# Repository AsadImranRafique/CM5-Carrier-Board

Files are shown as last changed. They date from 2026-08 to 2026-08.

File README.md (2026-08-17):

# CM4/CM5 Carrier Board V1

Production build of a compact carrier board for the Raspberry Pi Compute Module 4 and Compute Module 5. The board combines USB-C data and power, Ethernet, 25 W PoE input, M.2 storage and essential peripheral connections in a 120 mm × 40 mm form factor.

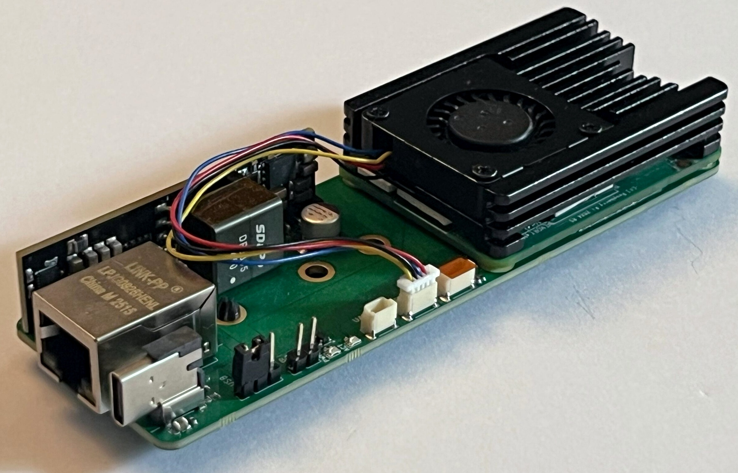
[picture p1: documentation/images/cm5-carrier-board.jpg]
Assembled CM4/CM5 Carrier Board V1


## Key Features

- Raspberry Pi Compute Module 4 and Compute Module 5 support
- Two 100-pin Hirose board-to-board connectors
- 120 mm × 40 mm board outline
- Six-layer PCB
- USB-C for data and 5 V at up to 3 A power input
- RJ45 Ethernet MagJack
- 25 W PoE powered-device input
- Jumper-selectable USB-C or PoE power input
- M.2 M-Key connector with support for 2230, 2242 and 2260 modules
- microSD card socket for Compute Module Lite variants
- 3-pin UART JST connector
- 3-pin I²C JST connector
- 3-pin PWM fan JST connector
- PWR and ACT indicator LEDs

## Power Input

The carrier board can be powered through either USB-C or PoE. The active input is selected using the onboard power-selection jumper.

The USB-C input provides 5 V at up to 3 A and uses CC pull-down resistors for source detection. The PoE interface operates as a 25 W powered device through the Ethernet connection.

## Storage

The M.2 M-Key interface supports 2230, 2242 and 2260 module sizes. A microSD card socket is provided for CM4 Lite and CM5 Lite variants without onboard eMMC storage.

## Peripheral Connections

UART, I²C and PWM fan connections are exposed through dedicated 3-pin JST connectors. PWR and ACT LEDs provide visible system-status indication.

## Repository Contents

This repository contains the KiCad design sources for the production V1 board, including:

- Schematic and PCB layout
- Project symbol and footprint libraries
- Component 3D models

## Opening the Project

1. Install [KiCad](https://www.kicad.org/).
2. Clone or download this repository.
3. Open `CM5Carrier.kicad_pro`.

## License

This hardware design is licensed under the [Apache License 2.0](LICENSE).

## Author

Designed by [Asad Imran](https://github.com/AsadImranRafique).

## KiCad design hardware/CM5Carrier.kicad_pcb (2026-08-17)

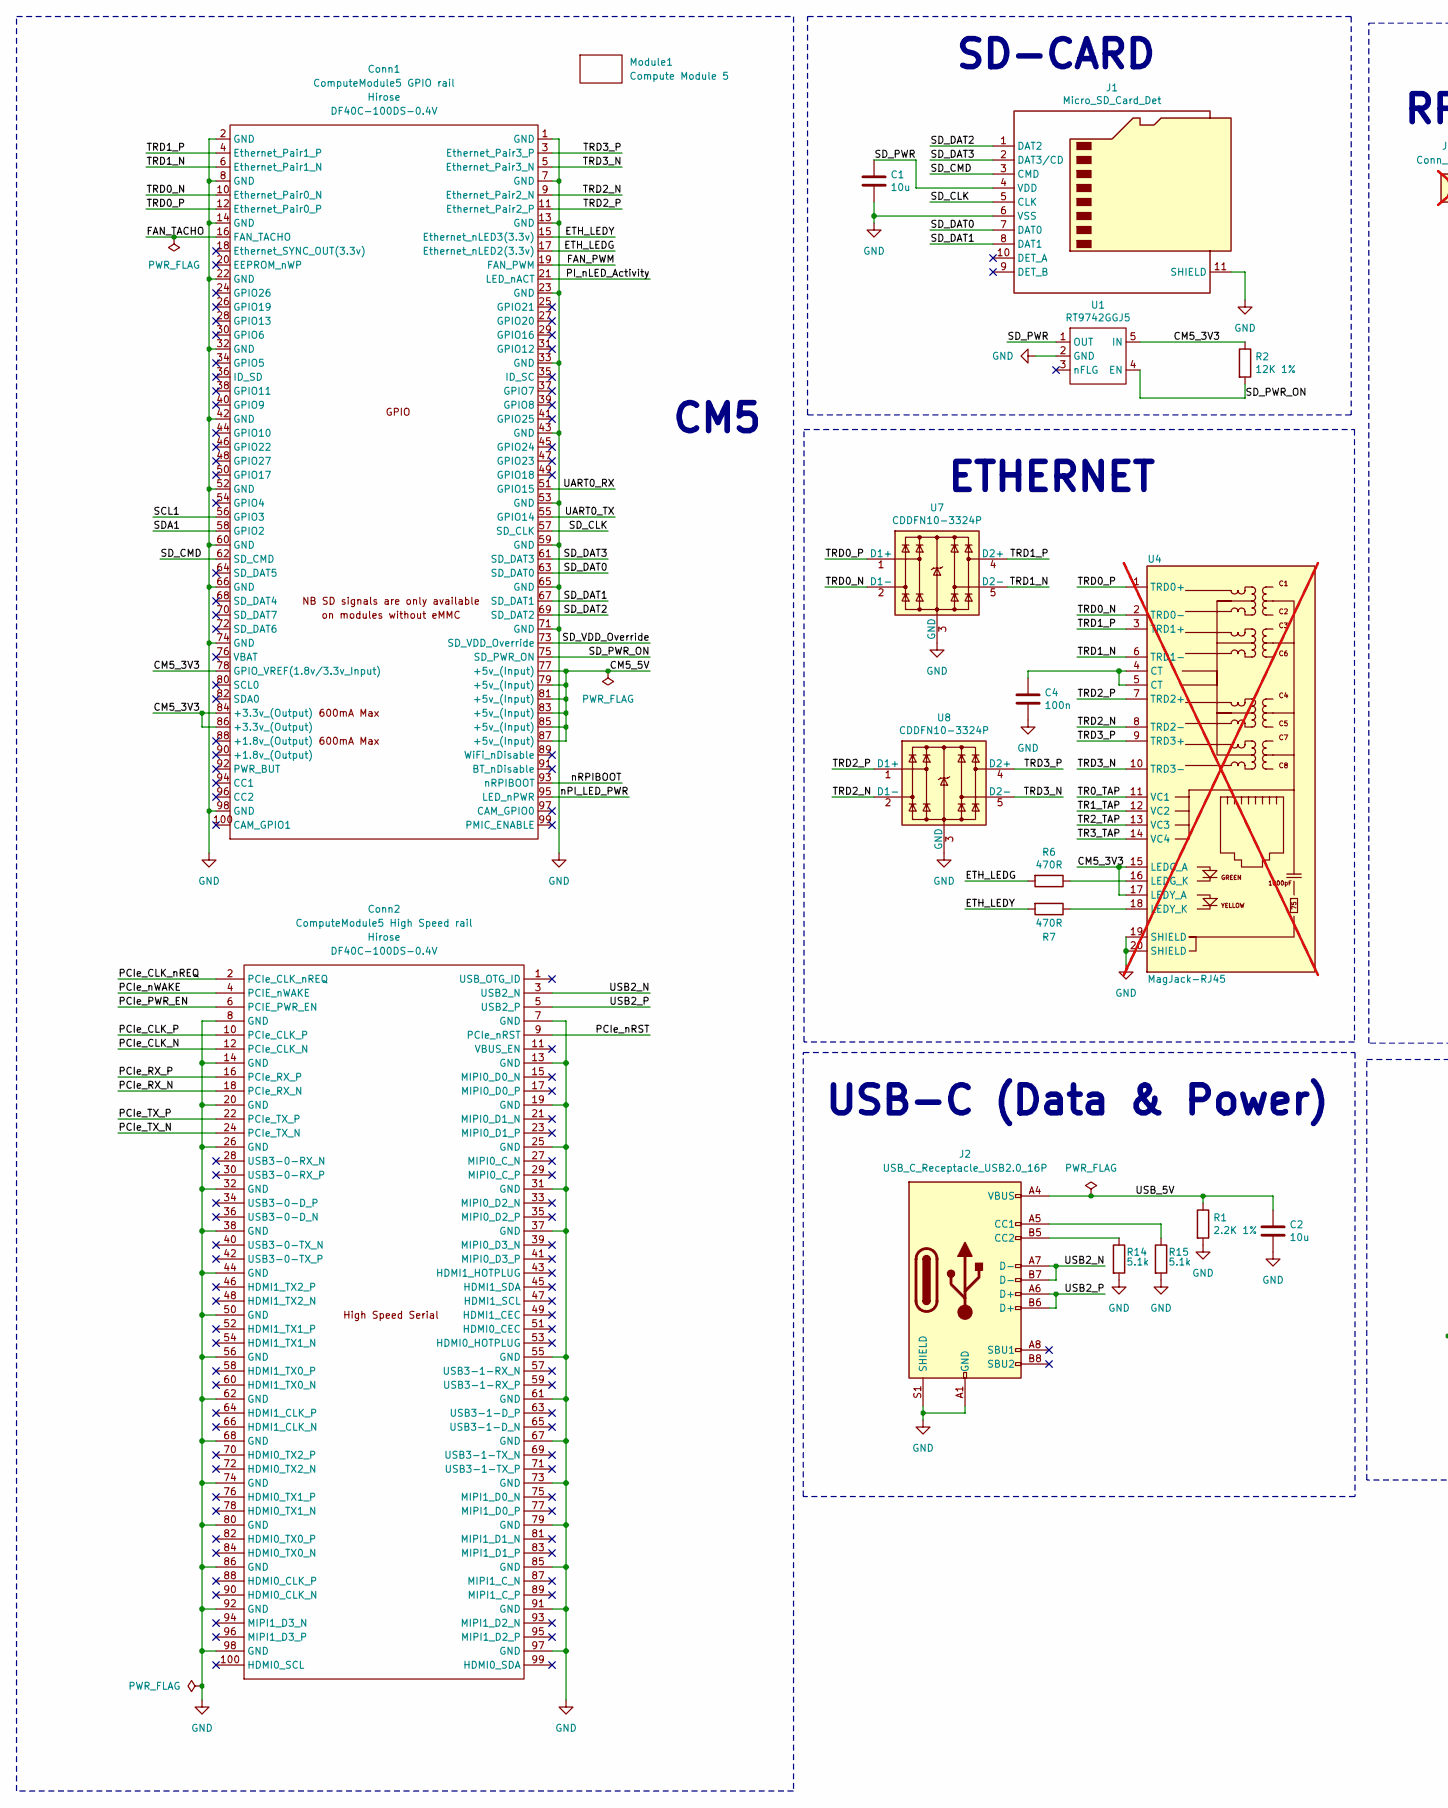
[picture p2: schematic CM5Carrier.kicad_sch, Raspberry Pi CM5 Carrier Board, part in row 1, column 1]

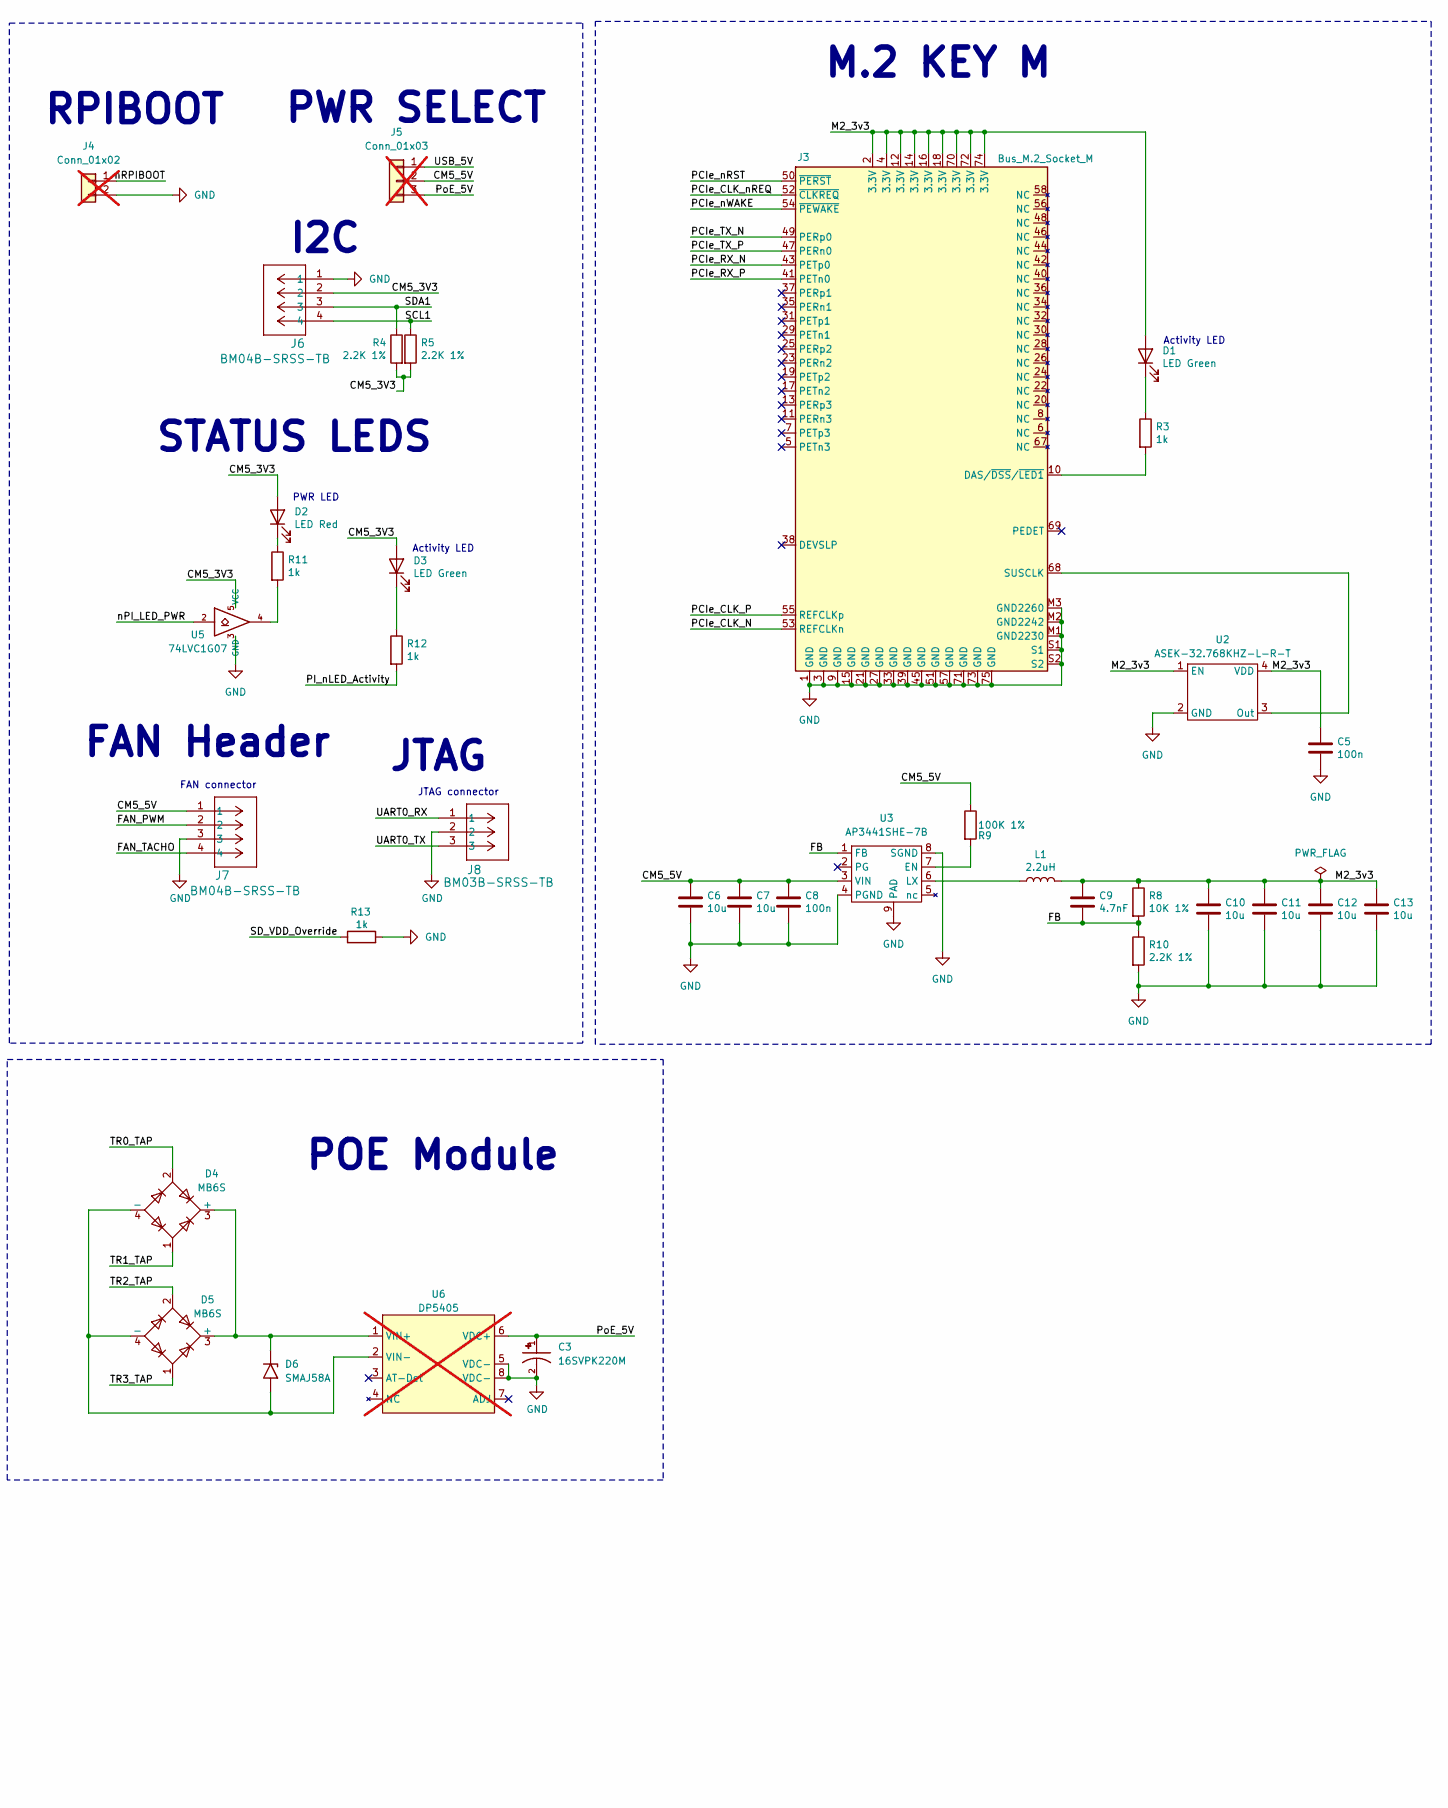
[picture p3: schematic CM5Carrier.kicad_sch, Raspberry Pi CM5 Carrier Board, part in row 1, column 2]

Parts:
C1, C2, C6, C7, C10, C11, C12, C13: 10u; C_0805_2012Metric; Part Number GRM21BR71A106KA73L
C3: 16SVPK220M; CAP_16SVPK220M; Part Number 16SVPK220M
C4, C5, C8: 100n; C_0402_1005Metric; Part Number EMK105B7104KV-F
C9: 4.7nF; C_0402_1005Metric; Part Number CC0402KRX7R9BB472
Conn1: ComputeModule5 GPIO rail; CONN_DF40C-100DS-0.4V51_HIR; Part Number DF40C-100DS-0.4V
Conn2: ComputeModule5 High Speed rail; CONN_DF40C-100DS-0.4V51_HIR; Part Number DF40C-100DS-0.4V
D1, D3: LED Green; LED_0603_1608Metric; Part Number LTST-C190GKT
D2: LED Red; LED_0603_1608Metric; Part Number LTST-C190KRKT
D4, D5: MB6S; TO-269AA; Part Number MB6S
D6: SMAJ58A; D_SMA; Part Number SMAJ58A
J1: Micro_SD_Card_Det; SDCARD_MOLEX_503398-1892; Part Number 5033981892
J2: USB_C_Receptacle_USB2.0_16P; USB4205-GF-A; Part Number USB4205-GF-A
J3: Bus_M.2_Socket_M; M.2 M Key socket; Part Number MDT320M03001
J4: Conn_01x02; PinHeader_1x02_P2.54mm_Vertical; Part Number G800W306018EU; not fitted
J5: Conn_01x03; PinHeader_1x03_P2.54mm_Vertical; Part Number G800W305018EU; not fitted
J6, J7: BM04B-SRSS-TB; JST_SH_BM04B-SRSS-TB_1x04-1MP_P1.00mm_Vertical; Part Number BM04B-SRSS-TB
J8: BM03B-SRSS-TB; JST_SH_BM03B-SRSS-TB_1x03-1MP_P1.00mm_Vertical; Part Number BM03B-SRSS-TB
L1: 2.2uH; L_Bourns_SRP5030CC; Part Number SRP5030CC-2R2M
Module1: Compute Module 5; Raspberry-Pi-5-Compute-Module
R1, R4, R5, R10: 2.2K 1%; R_0402_1005Metric; Part Number RC0402FR-072K2L
R2: 12K 1%; R_0402_1005Metric; Part Number RC0402FR-0712KL
R3, R11, R12, R13: 1k; R_0402_1005Metric; Part Number RC0402FR-071KL
R6, R7: 470R; R_0402_1005Metric; Part Number RC0402FR-07470RL
R8: 10K 1%; R_0402_1005Metric; Part Number RC0402FR-0710KL
R9: 100K 1%; R_0402_1005Metric; Part Number RC0402FR-07100KL
R14, R15: 5.1k; R_0603_1608Metric; Part Number RC0603FR-075K1L
U1: RT9742GGJ5; SOT-23-5; Part Number RT9742GGJ5
U2: ASEK-32.768KHZ-L-R-T; Crystal_SMD_3225-4Pin_3.2x2.5mm; Part Number ASEK-32.768KHZ-L-R-T
U3: AP3441SHE-7B; DFN-8-1EP_2x2mm_P0.5mm_EP1.05x1.75mm; Part Number AP3441SHE-7B
U4: MagJack-RJ45; TRJG0926HENL; Part Number LPJG0926HENL; not fitted
U5: 74LVC1G07; SOT-353_SC-70-5; Part Number 74LVC1G07
U6: DP5405; not fitted
U7, U8: CDDFN10-3324P; USON-10_2.5x1.0mm_P0.5mm; Part Number CDDFN10-3324P

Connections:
/CM5_3V3: Conn1.78 (GPIO_VREF(1.8v/3.3v_Input)), Conn1.84 (+3.3v_(Output)), Conn1.86 (+3.3v_(Output)), D2.2 (A), D3.2 (A), J6.2, R2.1, R4.2, R5.2, U1.5 (IN), U4.15 (LEDG_A), U4.17 (LEDY_A), U5.5 (VCC)
/CM5_5V: C6.1, C7.1, C8.1, Conn1.77 (+5v_(Input)), Conn1.79 (+5v_(Input)), Conn1.81 (+5v_(Input)), Conn1.83 (+5v_(Input)), Conn1.85 (+5v_(Input)), Conn1.87 (+5v_(Input)), J5.2, J7.1, R9.1, U3.3 (VIN)
/ETH_LEDG: Conn1.17 (Ethernet_nLED2(3.3v)), R6.2
/ETH_LEDY: Conn1.15 (Ethernet_nLED3(3.3v)), R7.2
/FAN_PWM: Conn1.19 (FAN_PWM), J7.2
/FAN_TACHO: Conn1.16 (FAN_TACHO), J7.4
/FB: C9.2, R8.2, R10.1, U3.1 (FB)
/M2_3v3: C5.1, C9.1, C10.1, C11.1, C12.1, C13.1, D1.2 (A), J3.2 (3.3V), J3.4 (3.3V), J3.12 (3.3V), J3.14 (3.3V), J3.16 (3.3V), J3.18 (3.3V), J3.70 (3.3V), J3.72 (3.3V), J3.74 (3.3V), L1.2, R8.1, U2.1 (EN), U2.4 (VDD)
/PCIe_CLK_N: Conn2.12 (PCIe_CLK_N), J3.53 (REFCLKn)
/PCIe_CLK_P: Conn2.10 (PCIe_CLK_P), J3.55 (REFCLKp)
/PCIe_CLK_nREQ: Conn2.2 (PCIe_CLK_nREQ), J3.52 (~CLKREQ)
/PCIe_PWR_EN: Conn2.6 (PCIE_PWR_EN)
/PCIe_RX_N: Conn2.18 (PCIe_RX_N), J3.43 (PETp0)
/PCIe_RX_P: Conn2.16 (PCIe_RX_P), J3.41 (PETn0)
/PCIe_TX_N: Conn2.24 (PCIe_TX_N), J3.49 (PERp0)
/PCIe_TX_P: Conn2.22 (PCIe_TX_P), J3.47 (PERn0)
/PCIe_nRST: Conn2.9 (PCIe_nRST), J3.50 (~PERST)
/PCIe_nWAKE: Conn2.4 (PCIE_nWAKE), J3.54 (~PEWAKE)
/PI_nLED_Activity: Conn1.21 (LED_nACT), R12.2
/PoE_5V: C3.1, J5.3, U6.6 (VDC+)
/SCL1: Conn1.56 (GPIO3), J6.4, R5.1
/SDA1: Conn1.58 (GPIO2), J6.3, R4.1
/SD_CLK: Conn1.57 (SD_CLK), J1.5 (CLK)
/SD_CMD: Conn1.62 (SD_CMD), J1.3 (CMD)
/SD_DAT0: Conn1.63 (SD_DAT0), J1.7 (DAT0)
/SD_DAT1: Conn1.67 (SD_DAT1), J1.8 (DAT1)
/SD_DAT2: Conn1.69 (SD_DAT2), J1.1 (DAT2)
/SD_DAT3: Conn1.61 (SD_DAT3), J1.2 (DAT3/CD)
/SD_PWR: C1.1, J1.4 (VDD), U1.1 (OUT)
/SD_PWR_ON: Conn1.75 (SD_PWR_ON), R2.2, U1.4 (EN)
/SD_VDD_Override: Conn1.73 (SD_VDD_Override), R13.1
/TR0_TAP: D4.2, U4.11 (VC1)
/TR1_TAP: D4.1, U4.12 (VC2)
/TR2_TAP: D5.2, U4.13 (VC3)
/TR3_TAP: D5.1, U4.14 (VC4)
/TRD0_N: Conn1.10 (Ethernet_Pair0_N), U4.2 (TRD0-), U7.2 (D1-), U7.9
/TRD0_P: Conn1.12 (Ethernet_Pair0_P), U4.1 (TRD0+), U7.1 (D1+), U7.10
/TRD1_N: Conn1.6 (Ethernet_Pair1_N), U4.6 (TRD1-), U7.5 (D2-), U7.6
/TRD1_P: Conn1.4 (Ethernet_Pair1_P), U4.3 (TRD1+), U7.4 (D2+), U7.7
/TRD2_N: Conn1.9 (Ethernet_Pair2_N), U4.8 (TRD2-), U8.2 (D1-), U8.9
/TRD2_P: Conn1.11 (Ethernet_Pair2_P), U4.7 (TRD2+), U8.1 (D1+), U8.10
/TRD3_N: Conn1.5 (Ethernet_Pair3_N), U4.10 (TRD3-), U8.5 (D2-), U8.6
/TRD3_P: Conn1.3 (Ethernet_Pair3_P), U4.9 (TRD3+), U8.4 (D2+), U8.7
/UART0_RX: Conn1.51 (GPIO15), J8.1
/UART0_TX: Conn1.55 (GPIO14), J8.3
/USB2_N: Conn2.3 (USB2_N), J2.A7 (D-), J2.B7 (D-)
/USB2_P: Conn2.5 (USB2_P), J2.A6 (D+), J2.B6 (D+)
/USB_5V: C2.1, J2.A4 (VBUS), J2.A9 (VBUS), J2.B4 (VBUS), J2.B9 (VBUS), J5.1, R1.1
/nPI_LED_PWR: Conn1.95 (LED_nPWR), U5.2
/nRPIBOOT: Conn1.93 (nRPIBOOT), J4.1
GND: C1.2, C2.2, C3.2, C4.2, C5.2, C6.2, C7.2, C8.2, C10.2, C11.2, C12.2, C13.2, Conn1.1 (GND), Conn1.2 (GND), Conn1.7 (GND), Conn1.8 (GND), Conn1.13 (GND), Conn1.14 (GND), Conn1.22 (GND), Conn1.23 (GND), Conn1.32 (GND), Conn1.33 (GND), Conn1.42 (GND), Conn1.43 (GND), Conn1.52 (GND), Conn1.53 (GND), Conn1.59 (GND), Conn1.60 (GND), Conn1.65 (GND), Conn1.66 (GND), Conn1.71 (GND), Conn1.74 (GND), Conn1.98 (GND), Conn2.7 (GND), Conn2.8 (GND), Conn2.13 (GND), Conn2.14 (GND), Conn2.19 (GND), Conn2.20 (GND), Conn2.25 (GND), Conn2.26 (GND), Conn2.31 (GND), Conn2.32 (GND), Conn2.37 (GND), Conn2.38 (GND), Conn2.44 (GND), Conn2.50 (GND), Conn2.55 (GND), Conn2.56 (GND), Conn2.61 (GND), Conn2.62 (GND), Conn2.67 (GND), Conn2.68 (GND), Conn2.73 (GND), Conn2.74 (GND), Conn2.79 (GND), Conn2.80 (GND), Conn2.85 (GND), Conn2.86 (GND), Conn2.91 (GND), Conn2.92 (GND), Conn2.97 (GND), Conn2.98 (GND), J1.6 (VSS), J1.11 (SHIELD), J2.A1 (GND), J2.A12 (GND), J2.B1 (GND), J2.B12 (GND), J2.S1 (SHIELD), J3.1 (GND), J3.3 (GND), J3.9 (GND), J3.15 (GND), J3.21 (GND), J3.27 (GND), J3.33 (GND), J3.39 (GND), J3.45 (GND), J3.51 (GND), J3.57 (GND), J3.71 (GND), J3.73 (GND), J3.75 (GND), J3.M1 (GND2230), J3.M2 (GND2242), J3.M3 (GND2260), J3.S1, J3.S2, J4.2, J6.1, J7.3, J8.2, R1.2, R10.2, R13.2, R14.2, R15.2, U1.2 (GND), U2.2 (GND), U3.4 (PGND), U3.8 (SGND), U3.9 (PAD), U4.19 (SHIELD), U4.20 (SHIELD), U5.3 (GND), U6.5 (VDC-), U6.8 (VDC-), U7.3 (GND), U7.8 (GND), U8.3 (GND), U8.8 (GND)
unnamed: C4.1, U4.4 (CT), U4.5 (CT)
unnamed: D1.1 (K), R3.1
unnamed: D2.1 (K), R11.1
unnamed: D3.1 (K), R12.1
unnamed: D4.3 (+), D5.3 (+), D6.1 (A1), U6.1 (VIN+)
unnamed: D4.4 (-), D5.4 (-), D6.2 (A2), U6.2 (VIN-)
unnamed: J2.A5 (CC1), R15.1
unnamed: J2.B5 (CC2), R14.1
unnamed: J3.10 (DAS/~DSS/~LED1), R3.2
unnamed: J3.68 (SUSCLK), U2.3 (Out)
unnamed: R11.2, U5.4
unnamed: R9.2, U3.7 (EN)
unnamed: L1.1, U3.6 (LX)
unnamed: R6.1, U4.16 (LEDG_K)
unnamed: R7.1, U4.18 (LEDY_K)

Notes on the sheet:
USB-C (Data & Power)
JTAG connector
I2C
M.2 KEY M
POE Module
PWR SELECT
STATUS LEDS
Activity LED
PWR LED
FAN Header
FAN connector
RPIBOOT
JTAG
ETHERNET
CM5
SD-CARD

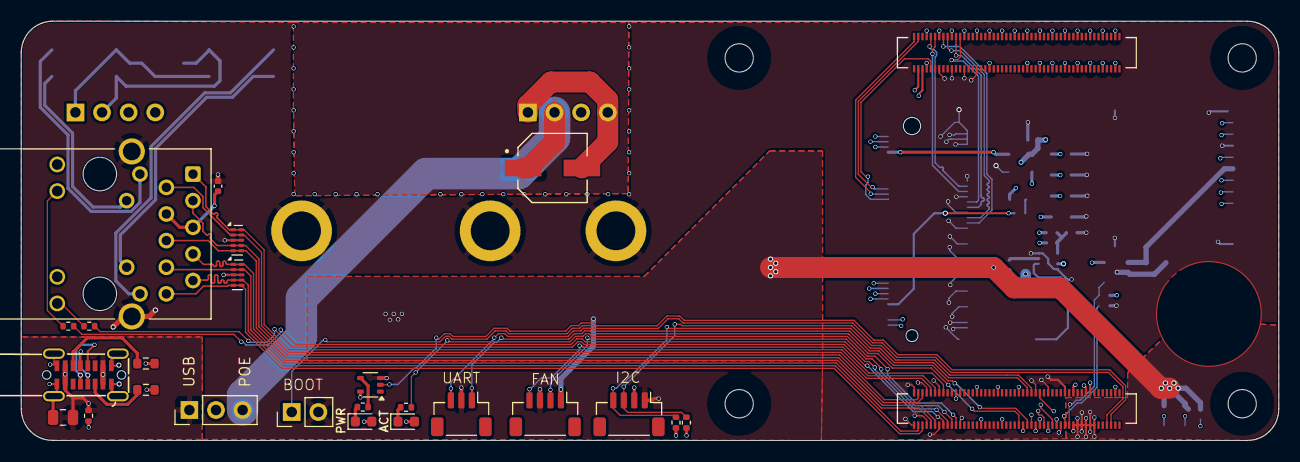
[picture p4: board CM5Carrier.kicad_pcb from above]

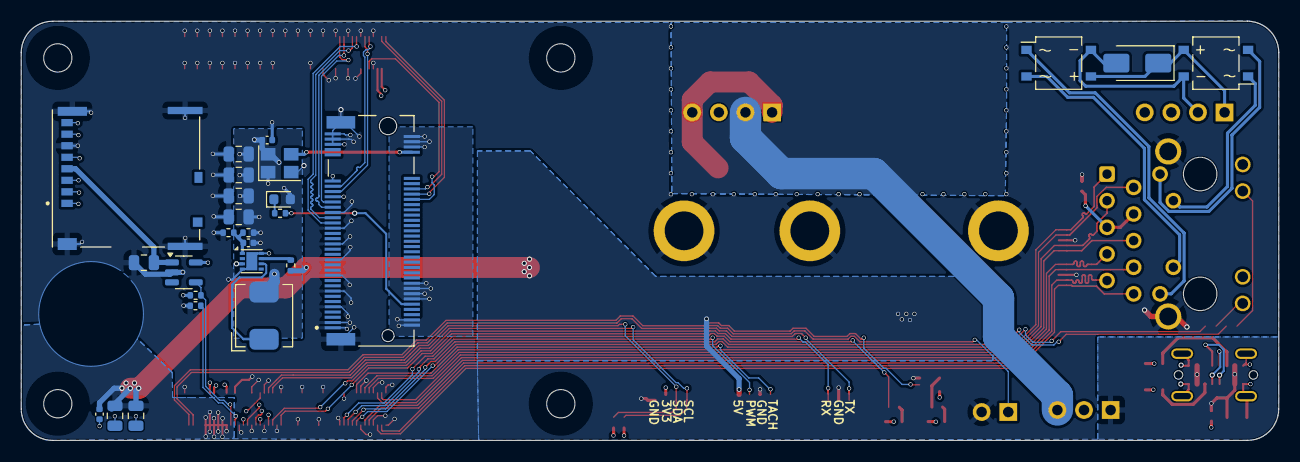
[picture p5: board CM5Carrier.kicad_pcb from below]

Board: 6 copper layers, 120.0 x 40.0 mm, 54 parts (26 on the bottom side), 65 nets.

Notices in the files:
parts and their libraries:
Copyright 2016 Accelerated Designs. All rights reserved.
